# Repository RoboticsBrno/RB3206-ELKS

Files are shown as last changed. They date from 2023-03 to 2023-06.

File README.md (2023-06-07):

# RB3206-ELKS

<p align="center">


</p>

ELKS aka **ESP Learning Kit Starter** is a development board for the ESP32-S3 microcontroller.
It's an educational tool for teaching electronics and embedded programming.
We employ it ourselves in courses for beginners and advanced students.

It can be powered by a USB cable or power bank coupled directly with the board.
This way you can take your ELKS with you anywhere and use it for your on-the-go projects.

## Features:
- Conventional LEDs
- Buttons
- Potentiometers
- Buzzer
- Servo outputs
- Digilent PMOD connectors

<div align="center">
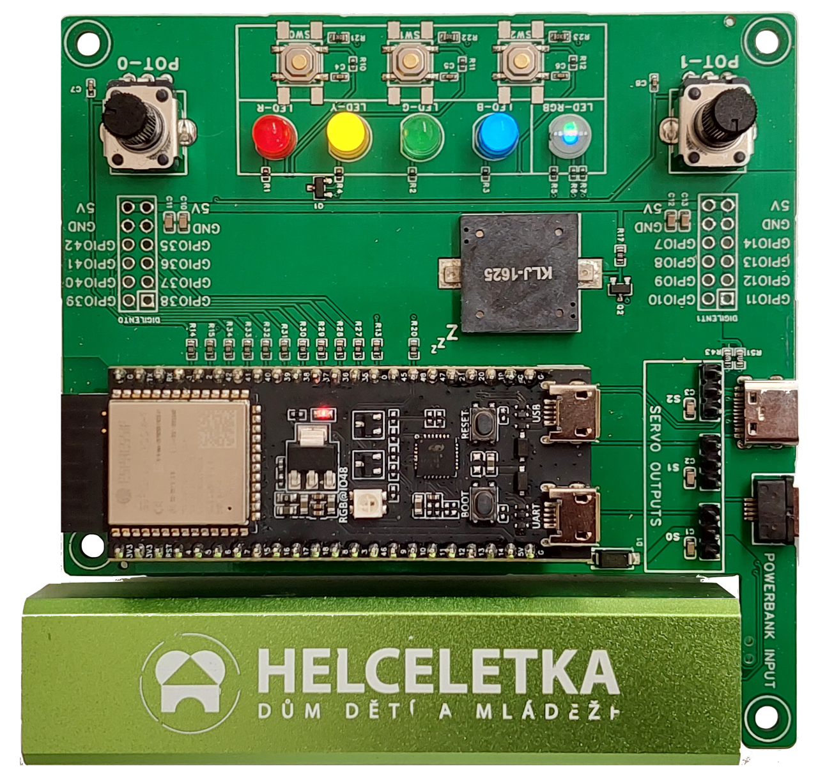
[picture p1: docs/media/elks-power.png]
    
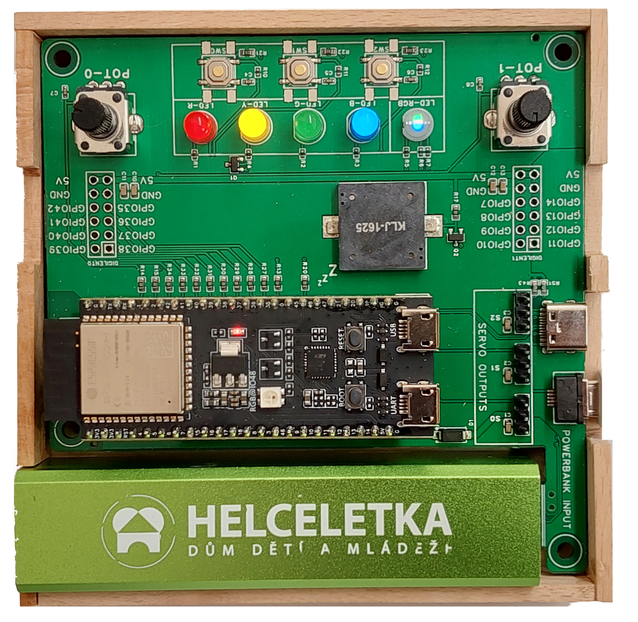
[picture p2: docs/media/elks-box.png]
    
</div>

<div align="center">
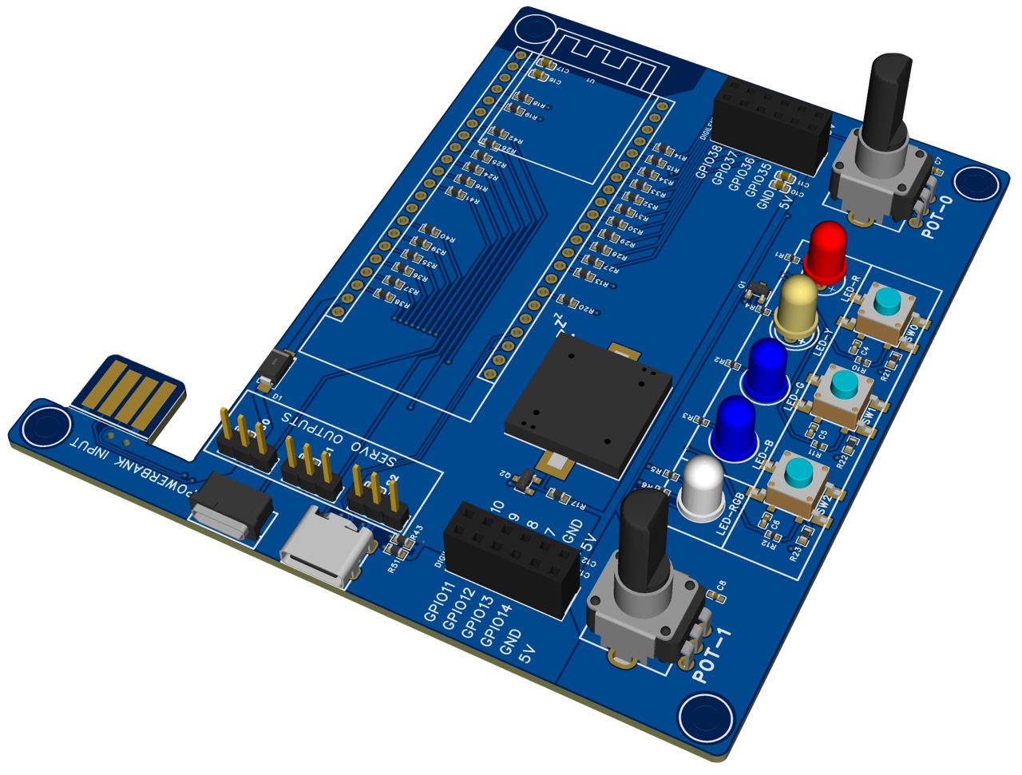
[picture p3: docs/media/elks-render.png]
    
</div>

## [With the support of Espressif Systems](https://www.espressif.com/)

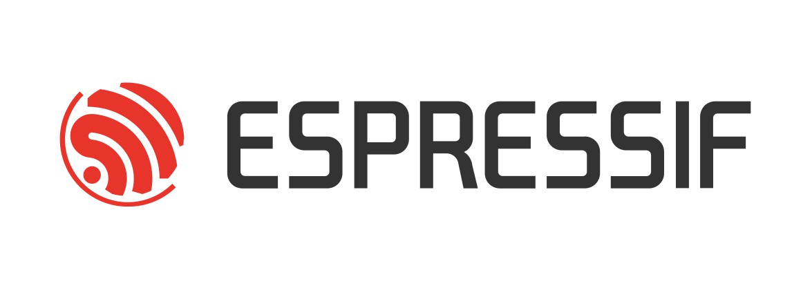
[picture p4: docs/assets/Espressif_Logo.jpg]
Espressif Systems (https://www.espressif.com/)


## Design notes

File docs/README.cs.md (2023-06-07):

# RB3206-ELKS

<p align="center">


</p>

ELKS neboli **ESP Learning Kit Starter** je vývojová deska pro mikrokontrolér ESP32-S3.
Jedná se o vzdělávací nástroj pro výuku elektroniky a základů programování.
Kity používáme v kroužcích pro začátečníky i pokročilé.

Desku lze napájet pomocí USB kabelu nebo power banky připojené přímo k desce.

## Funkce:
- LED
- Tlačítka
- Potenciometry
- Bzučák
- Servo výstupy
- Digilent PMOD konektory

<div align="center">
    
    
</div>

<div align="center">
    
</div>

## [S podporou Espressif Systems](https://www.espressif.com/)

Espressif Systems (https://www.espressif.com/)

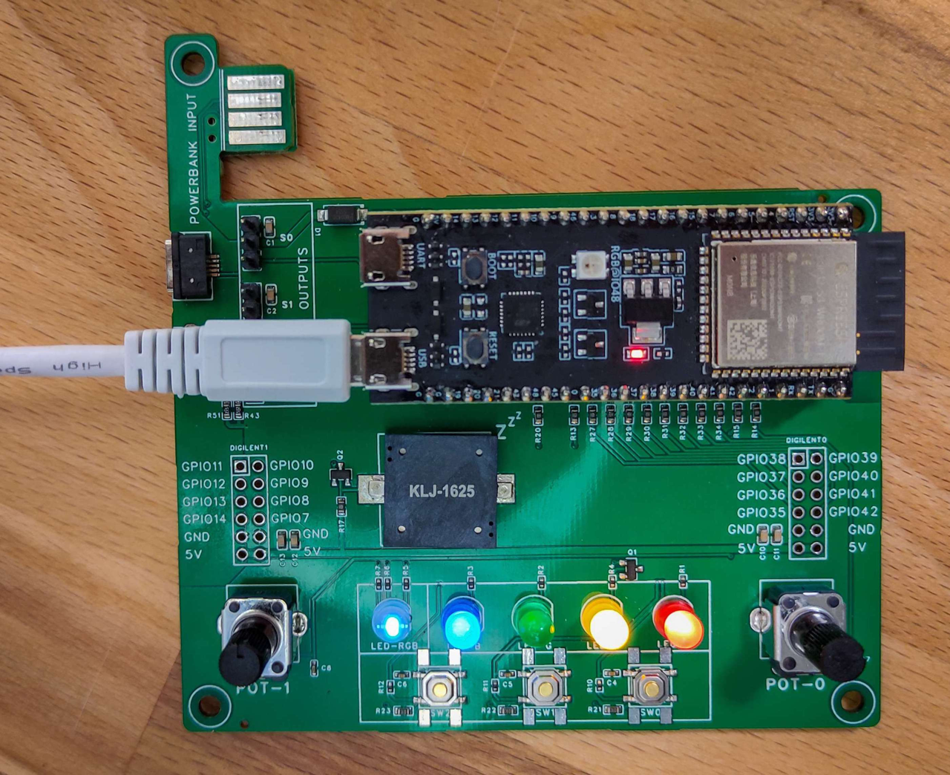
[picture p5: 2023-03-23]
docs/media/elks.png

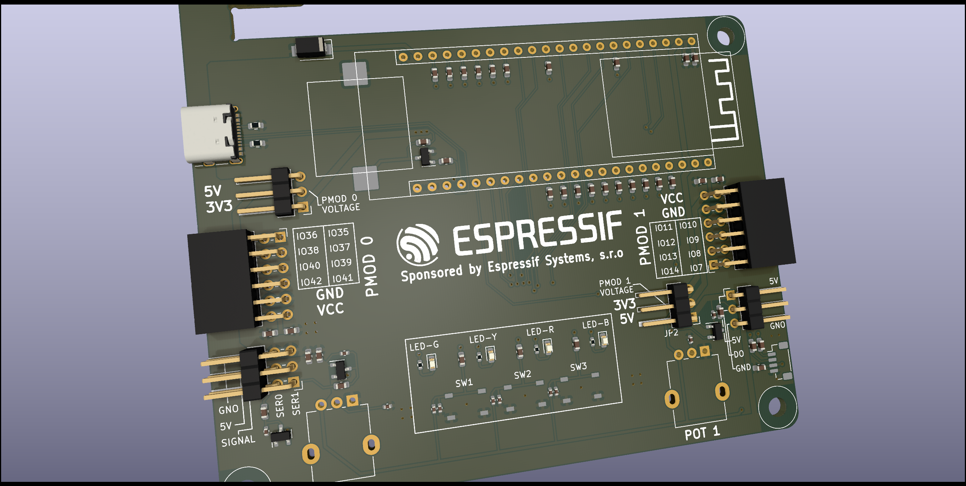
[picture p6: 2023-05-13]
HW/ELKS/ELKS.png

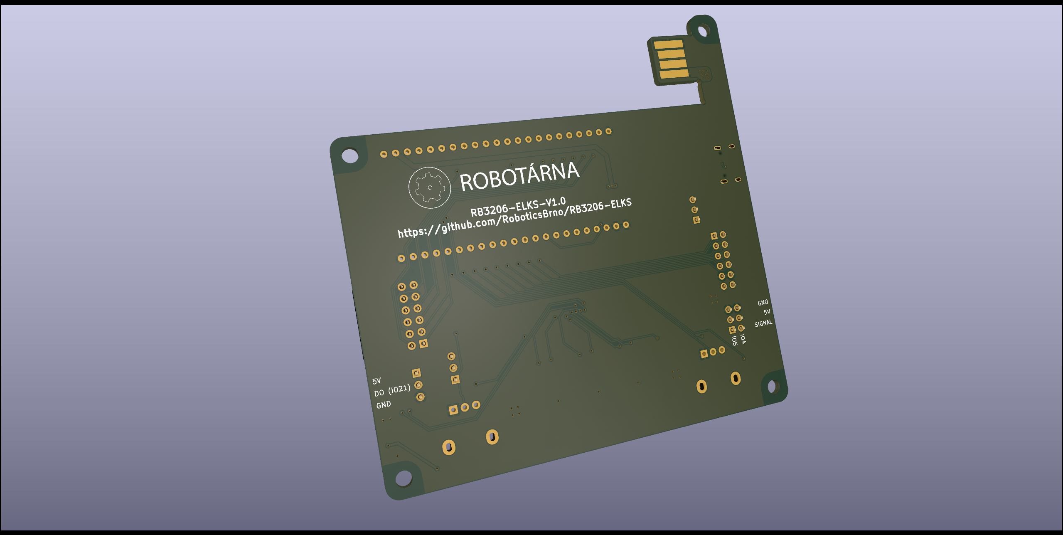
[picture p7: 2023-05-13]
HW/ELKS/ELKS_b.png

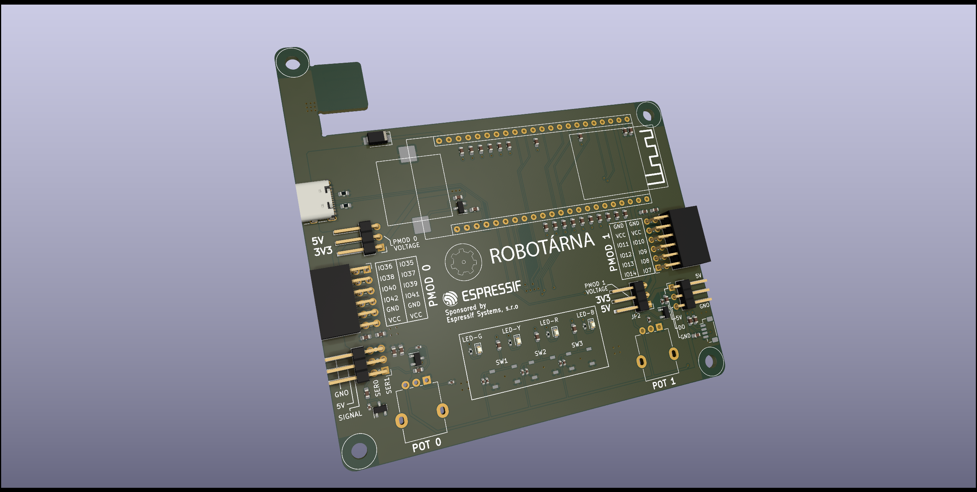
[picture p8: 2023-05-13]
HW/ELKS/ELKS_f.png

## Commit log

2023-01-15 Schematic
    ESP32-S3-DevkitC-1
    3*button
    2*potentiometer
    LED - red, green, blue, yellow and RGB
    Buzzer
    Phototransistor
    3*servo connector
    2*Connector for extranal devices, compatible with Digilent Pmod™
    power input, USB-C, micro USB, PCB-USB, spring clamps
2023-01-15 Protection resistors and button capacitors
    180ohm protection resistors for all externally usable pins
    R = 330ohm c = 100nF low pass filter for buttons
    10uF capacitors for extranal devices conectors
2023-01-17 Full PCB design
    Since ESP32 doesn't have many pins, I merged the LED-B input and the phototrasistor output =>
    The user cannot use the blue LED and the phototransistor at the same time.
2023-01-17 Change LED-B/PHOTO and SW2 pins
    The phototransistor needed an ADC pin, so it was connected to GPIO6 where SW2 was.
2023-01-17 Simplified buzzer circuit
2023-01-20 Redesign
    USB programming connection to USB-C, Micro-USB and power bank USB on PCB
    Remove
    - phototransistor
    - power terminal block
    Relocation
    - potentiometers
    - buttons
    - LEDs
    - Buzzer
    - Power Conector
    - Digilent Conectors
2023-01-20 Adding secondary buttons
2023-01-31 Removing copper under the ESP antenna
2023-02-12 Production files
    [BOM_Board1_PCB1_2023-02-12.xlsx, PickAndPlace_PCB1_2023-02-12.xlsx]
2023-02-12 File organization
    [BOM_Board1_PCB1_2023-02-12.csv, BOM_Board1_PCB1_2023-02-12.xlsx, PickAndPlace_PCB1_2023-02-12.csv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]
2023-04-14 Translating the schematic into KiCad
    [ELKS.kicad_pcb, ELKS.kicad_sch, ESP32S3.kicad_sch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]
2023-05-12 Laskakit I2C connector
    [ELKS.kicad_pcb, ELKS.kicad_sch, conectors.kicad_sch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]
2023-05-13 KiCad PDB
    [ELKS.kicad_pcb, ELKS.kicad_sch, conectors.kicad_sch]
2023-05-13 Logos and labels
    [ELKS.kicad_pcb]
2023-05-18 Fix PMOD1 VCC and GND order
    [ELKS.kicad_pcb]
2023-05-18 Fix position of PMOD voltage silkscreen
    [ELKS.kicad_pcb]
2023-05-18 Add PMOD silkscreen orientation unambiguity
    [ELKS.kicad_pcb]
2023-05-18 Make top logos nice
    [ELKS.kicad_pcb]
2023-05-18 Update bot logo
    [ELKS.kicad_pcb]
2023-05-18 Align bot silkscreen
    [ELKS.kicad_pcb]
2023-05-18 GNO -> GND
    [ELKS.kicad_pcb]
2023-05-18 Fix Servos silkscreen
    [ELKS.kicad_pcb]
2023-05-18 Change I-LED connector pinout to match servo connectors
    [ELKS.kicad_pcb, conectors.kicad_sch]
2023-05-19 Solve DRC errors
    [ELKS.kicad_pcb]
2023-05-22 Pin name
    [ELKS.kicad_pcb, ELKS.kicad_sch, conectors.kicad_sch]
2023-05-23 JST connector
    [ELKS.kicad_pcb, ELKS.kicad_sch, conectors.kicad_sch]
2023-05-25 Kikit JLC export
    [ELKS-CmtUser.gbr, ELKS-CuBottom.gbl, ELKS-CuTop.gtl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]
2023-06-06 Fix potentiometers footprints and relocation of two component
    [ELKS.kicad_pcb, ELKS.kicad_sch, ui.kicad_sch]
2023-06-06 Fix potentiometers footprints and relocation two component
    [ELKS.kicad_pcb, ELKS.kicad_sch, conectors.kicad_sch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]
2023-06-07 Levelshifter fix
    [ELKS.kicad_pcb, ELKS.kicad_sch, conectors.kicad_sch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]
2023-06-07 Solve RDC error
    [ELKS.kicad_pcb]
2023-06-11 Label of buzzer pin and Laska connector PULL-UP rezistors
    [ELKS.kicad_pcb, ELKS.kicad_sch, conectors.kicad_sch]
2023-06-12 Devkit pin headers, ADC to PMODs connectors, moving buttons and LEDs
    [ELKS.kicad_pcb, ELKS.kicad_sch, conectors.kicad_sch]
2023-06-12 USB shift
    [ELKS.kicad_pcb, ui.kicad_sch]
2023-06-15 Buzzer connected directly to ESP, UES diodes
    [ELKS.kicad_pcb, ELKS.kicad_sch, conectors.kicad_sch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]
2024-02-29 Cleaning files
    [BOM_Board1_PCB1_2023-02-12.csv, ELKS.kicad_sch, PickAndPlace_PCB1_2023-02-12.csv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]
2024-02-29 Silkscreen labels
    [ELKS.kicad_pcb]
2024-09-08 Mirroring of PMOD connectors
    [ELKS.kicad_pcb, conectors.kicad_sch]
